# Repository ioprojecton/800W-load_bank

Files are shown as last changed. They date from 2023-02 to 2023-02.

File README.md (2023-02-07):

# 800W Load bank for generators

800W load bank for load test 1KW generators.
2steps each 400W via switch

## Authors

- [@ioprojecton](https://www.github.com/ioprojecton)

## Screenshots

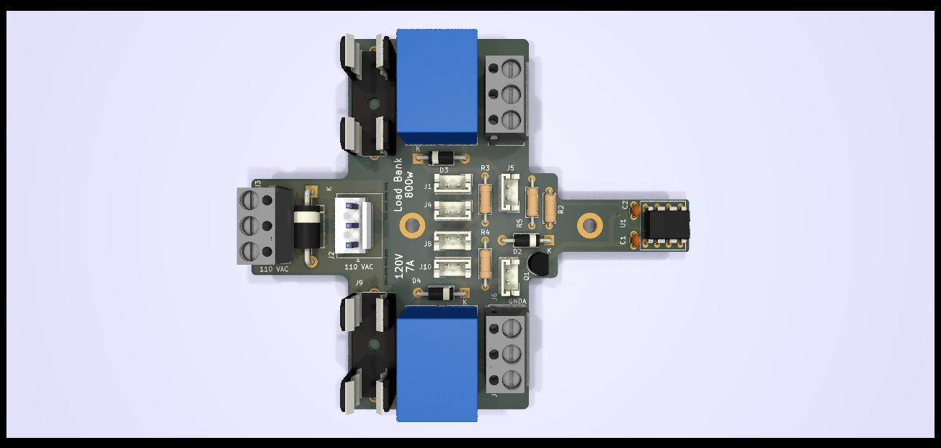
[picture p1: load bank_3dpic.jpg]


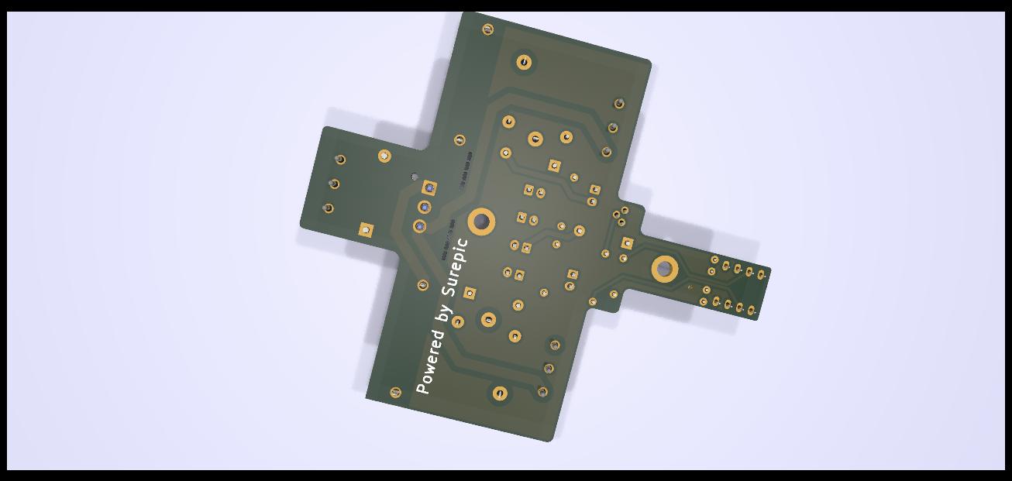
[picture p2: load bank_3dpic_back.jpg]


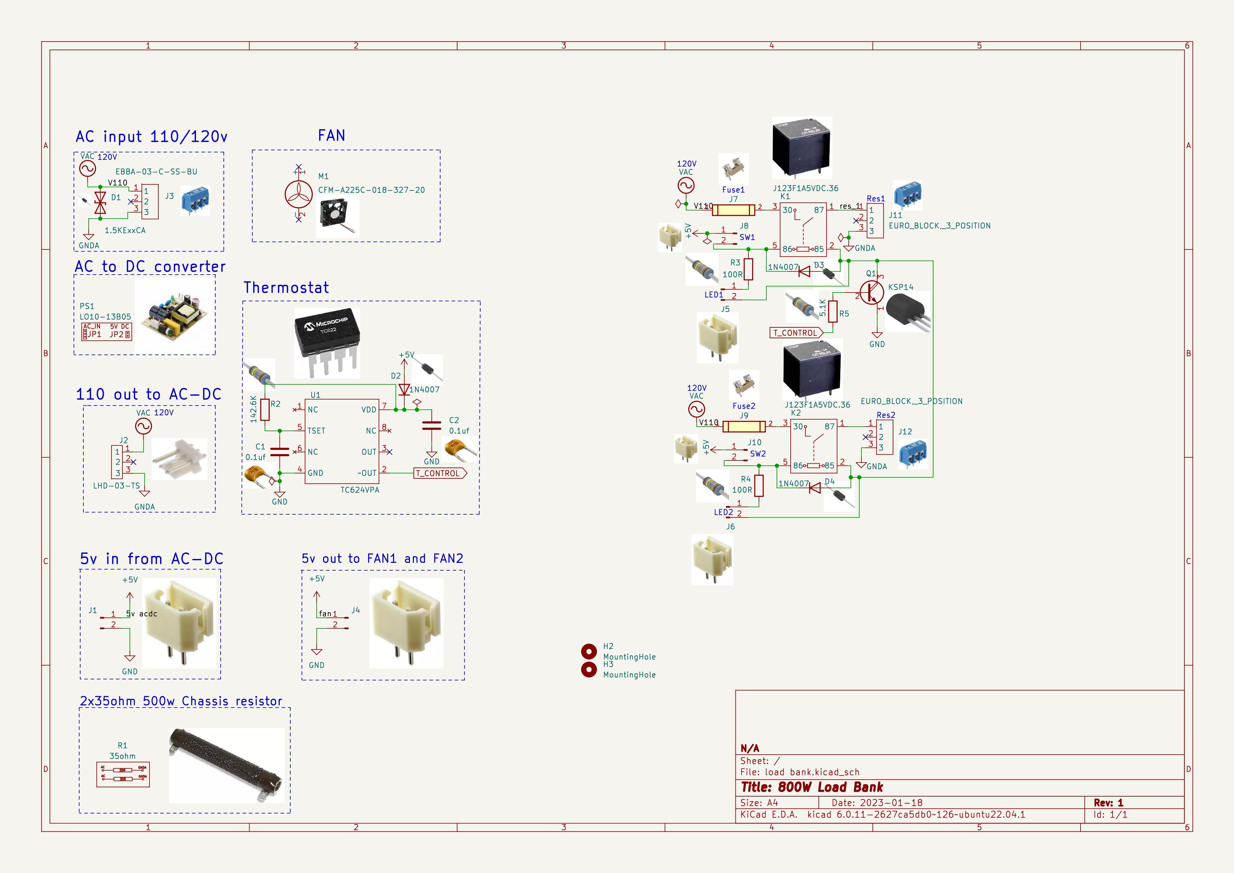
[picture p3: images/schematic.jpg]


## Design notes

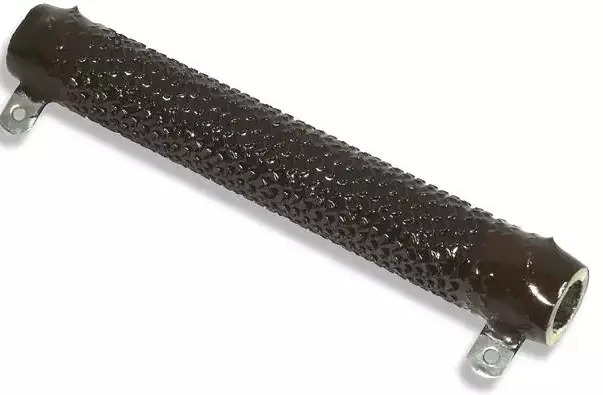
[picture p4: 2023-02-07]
images/chassis_resistor.jpg

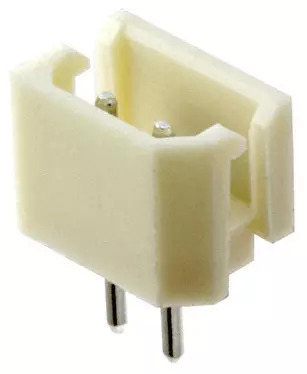
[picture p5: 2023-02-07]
images/25SH-B-02-TS.jpg

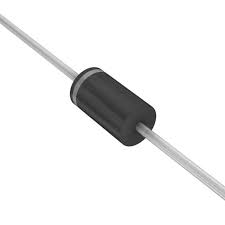
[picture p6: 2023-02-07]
images/tvs.jpeg

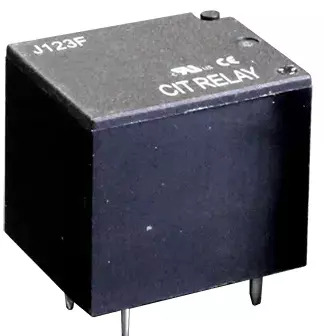
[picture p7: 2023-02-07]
images/relay.jpg

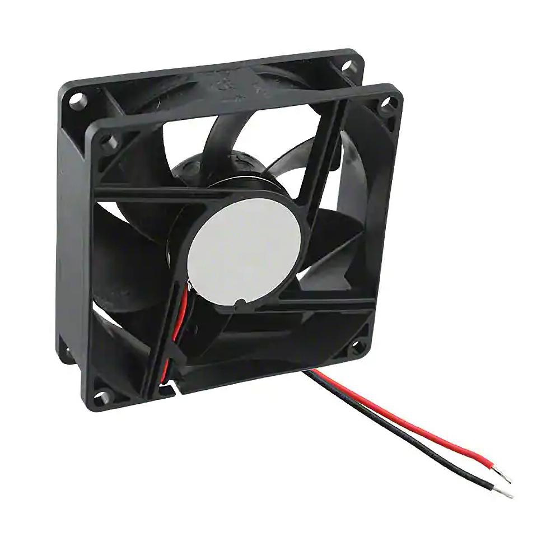
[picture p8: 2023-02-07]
images/fan.jpg

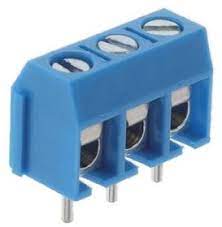
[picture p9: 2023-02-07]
images/euroblock3p.jpeg

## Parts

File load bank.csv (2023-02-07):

Source: | /home/plutus/load bank/load bank.kicad_sch
Date: | Mon 06 Feb 2023 08:38:23 PM
Tool: | Eeschema 6.0.11-2627ca5db0~126~ubuntu22.04.1
Generator: | /usr/share/kicad/plugins/bom_csv_grouped_by_value_with_fp.py
Component Count: | 31
Ref | Qnty | Value | Cmp name | Footprint | Description | Vendor
C1, C2, | 2 | 0.1uf | C | Capacitor_THT:C_Disc_D3.0mm_W1.6mm_P2.50mm | Unpolarized capacitor
D1, | 1 | 1.5KExxCA | 1.5KExxCA | Diode_THT:D_DO-201AE_P15.24mm_Horizontal | 1500W bidirectional TRANSZORB® Transient Voltage Suppressor, DO-201AE
D2, D3, D4, | 3 | 1N4007 | 1N4007 | Diode_THT:D_DO-41_SOD81_P10.16mm_Horizontal | 1000V 1A General Purpose Rectifier Diode, DO-41
J1, J4, J8, J10, | 4 | 25SH-B-02-TS | Conn_01x02_Male | Connector_JST:JST_EH_B2B-EH-A_1x02_P2.50mm_Vertical | Generic connector, single row, 01x02, script generated (kicad-library-utils/schlib/autogen/connector/)
J2, | 1 | LHD-03-TS | LHD-03-TS | Connector_JST:JST_VH_B3P-VH-FB-B_1x03_P3.96mm_Vertical
J3, | 1 | EBBA-03-C-SS-BU | EURO_BLOCK,_3_POSITION_1 | load bank:EURO_BLOCK,_3_POSITION
J5, J6, | 2 | Conn_01x02_Male | Conn_01x02_Male | Connector_JST:JST_EH_B2B-EH-A_1x02_P2.50mm_Vertical | Generic connector, single row, 01x02, script generated (kicad-library-utils/schlib/autogen/connector/)
J7, J9, | 2 | 696101000002 | 696101000002_1 | 696101000002:696101000002
J11, J12, | 2 | EURO_BLOCK,_3_POSITION | EURO_BLOCK,_3_POSITION_2 | load bank:EURO_BLOCK,_3_POSITION
K1, K2, | 2 | J123F1A5VDC.36 | J123F1A5VDC.36_1 | Relay_THT:Relay_SPST_SANYOU_SRD_Series_Form_A
M1, | 1 | CFM-A225C-018-327-20 | Fan |  | Fan
PS1, | 1 | LO10-13B05 | LO10-13B05
Q1, | 1 | KSP14 | Q_NPN_Darlington_EBC | load bank:KSP13 | NPN Darlington transistor, emitter/base/collector
R1, | 1 | 35ohm | Chassis_resistor_1
R2, | 1 | 142.6K | R | Resistor_THT:R_Axial_DIN0207_L6.3mm_D2.5mm_P7.62mm_Horizontal | Resistor
R3, R4, | 2 | 100R | R | Resistor_THT:R_Axial_DIN0207_L6.3mm_D2.5mm_P10.16mm_Horizontal | Resistor
R5, | 1 | 5.1K | R | Resistor_THT:R_Axial_DIN0207_L6.3mm_D2.5mm_P10.16mm_Horizontal | Resistor
U1, | 1 | TC624VPA | TC624VAT | load bank:DIP-8_300_ELL

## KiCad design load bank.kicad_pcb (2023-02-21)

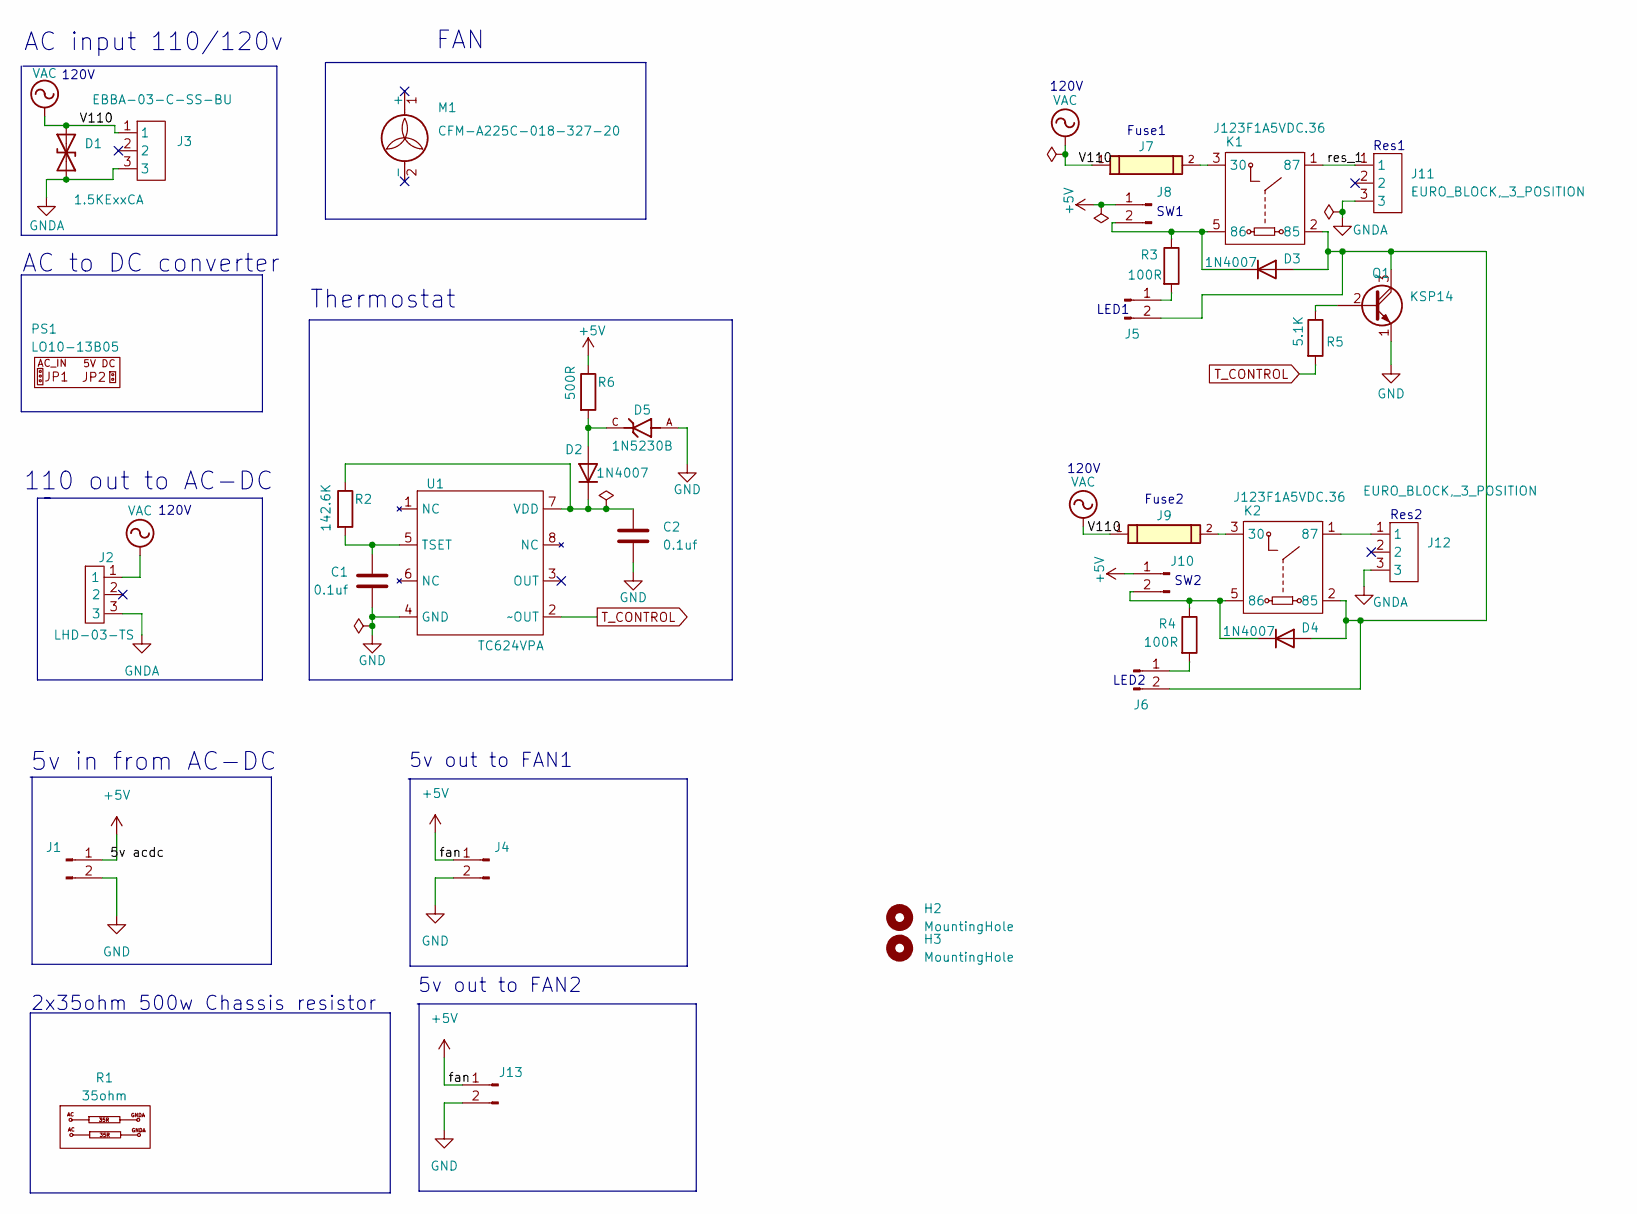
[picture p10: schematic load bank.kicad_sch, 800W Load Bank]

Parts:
C1, C2: 0.1uf; C_Disc_D3.0mm_W1.6mm_P2.50mm
D1: 1.5KExxCA; D_DO-201AE_P15.24mm_Horizontal
D2, D3, D4: 1N4007; D_DO-41_SOD81_P10.16mm_Horizontal
D5: 1N5230B; DIOAD928W47L399D179; PARTREV G1804
H2, H3: MountingHole; MountingHole_3.2mm_M3_DIN965_Pad_TopBottom
J1, J4, J8, J10, J13: 25SH-B-02-TS; JST_EH_B2B-EH-A_1x02_P2.50mm_Vertical
J2: LHD-03-TS; JST_VH_B3P-VH-FB-B_1x03_P3.96mm_Vertical
J3: EBBA-03-C-SS-BU; EURO_BLOCK,_3_POSITION
J5, J6: Conn_01x02_Male; JST_EH_B2B-EH-A_1x02_P2.50mm_Vertical
J7, J9: 696101000002; PART-NUMBER 696101000002
J11, J12: EURO_BLOCK,_3_POSITION
K1, K2: J123F1A5VDC.36; Relay_SPST_SANYOU_SRD_Series_Form_A
M1: CFM-A225C-018-327-20
PS1: LO10-13B05
Q1: KSP14; KSP13
R1: 35ohm
R2: 142.6K; R_Axial_DIN0207_L6.3mm_D2.5mm_P7.62mm_Horizontal
R3, R4: 100R; R_Axial_DIN0207_L6.3mm_D2.5mm_P10.16mm_Horizontal
R5: 5.1K; R_Axial_DIN0207_L6.3mm_D2.5mm_P10.16mm_Horizontal
R6: 500R; R_Axial_DIN0207_L6.3mm_D2.5mm_P7.62mm_Horizontal
U1: TC624VPA; DIP-8_300_ELL

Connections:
+5V: J1.1, J4.1, J8.1, J10.1, J13.1, R6.1
/res_1: J11.1, K1.1 (87)
GND: C1.1, C2.2, D5.A, J1.2, J4.2, J13.2, Q1.1 (E), U1.4 (GND)
GNDA: D1.1 (A1), J2.3, J3.3, J11.3, J12.3
unnamed: D2.2 (A), D5.C, R6.2
unnamed: C2.1, D2.1 (K), R2.1, U1.7 (VDD)
unnamed: D3.2 (A), D4.2 (A), J5.2, J6.2, K1.2 (85), K2.2 (85), Q1.3 (C)
unnamed: D3.1 (K), J8.2, K1.5 (86), R3.1
unnamed: D4.1 (K), J10.2, K2.5 (86), R4.1
unnamed: J5.1, R3.2
unnamed: J6.1, R4.2
unnamed: J7.2, K1.3 (30)
unnamed: J9.2, K2.3 (30)
unnamed: J12.1, K2.1 (87)
unnamed: Q1.2 (B), R5.1
unnamed: C1.2, R2.2, U1.5 (TSET)
T_CONTROL: R5.2, U1.2 (~OUT)
VAC: D1.2 (A2), J2.1, J3.1, J7.1, J9.1

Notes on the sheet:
110 out to AC-DC
SW1
Thermostat
AC to DC converter
Res1
SW2
LED1
Res2
AC input 110/120v
120V
2x35ohm 500w Chassis resistor
5v out to FAN2
LED2
Fuse1
5v in from AC-DC
5v out to FAN1
Fuse2
FAN

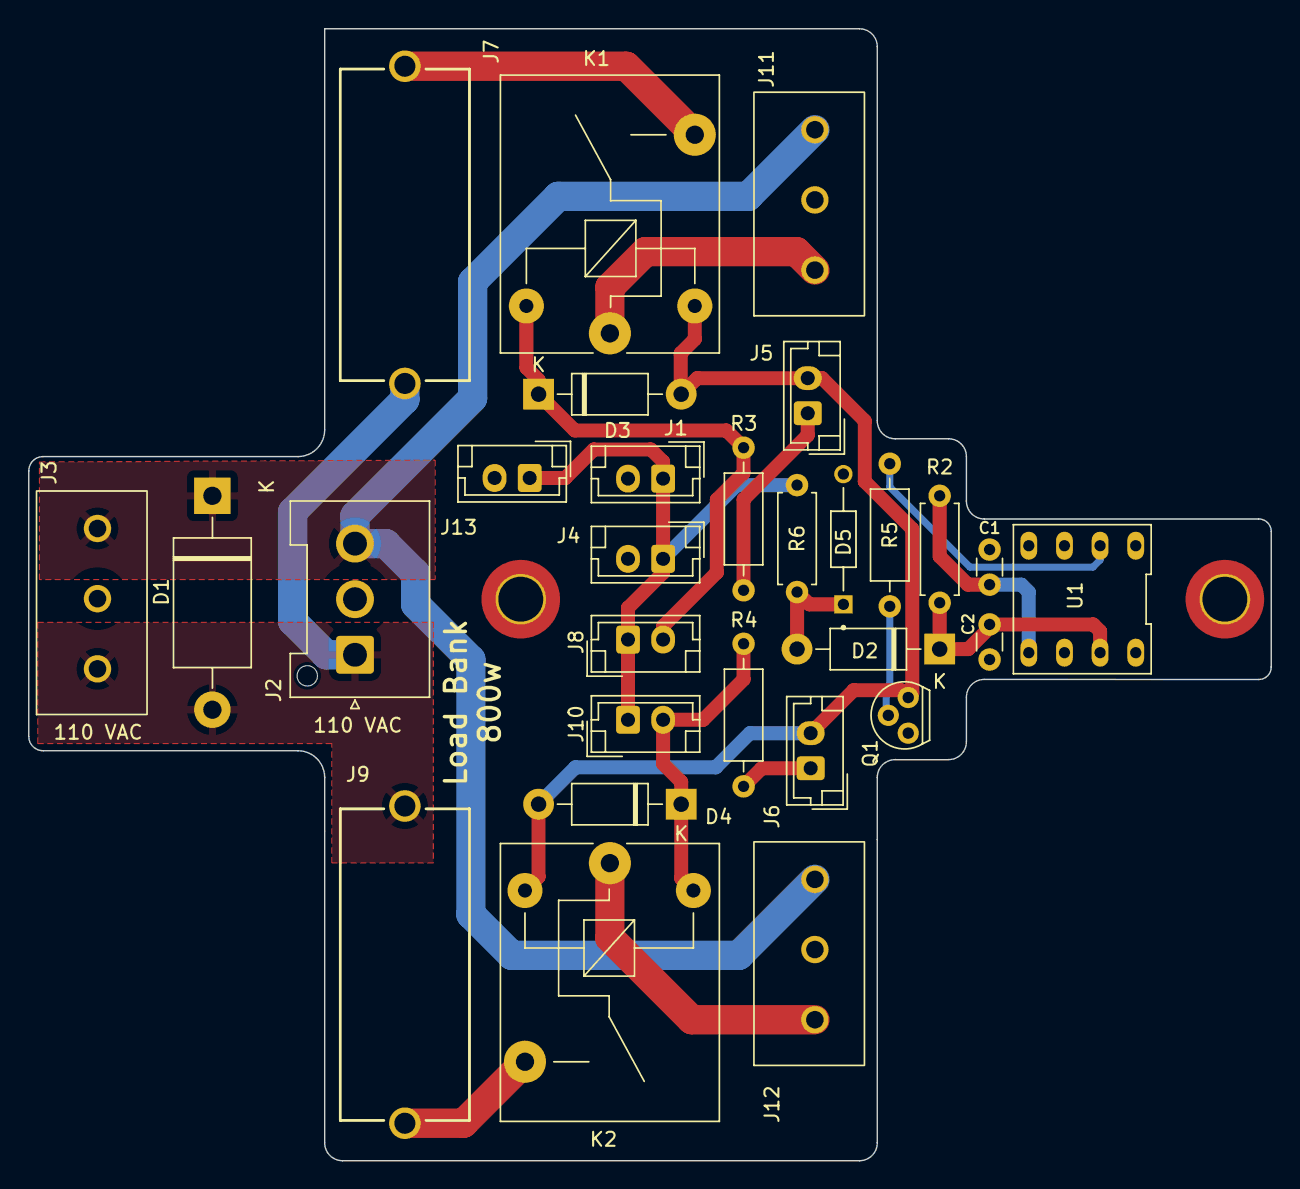
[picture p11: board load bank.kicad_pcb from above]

Board: 2 copper layers, 88.5 x 80.6 mm, 31 parts (0 on the bottom side), 18 nets.

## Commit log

2023-02-07 added BOM
    [load bank.csv]
2023-02-07 added schematic jpg
2023-02-07 added backside of pcb
2023-02-17 added second fan connector for parallel connection
    [load bank.kicad_sch]
2023-02-17 updated pcb with fan2 connector
    [load bank.kicad_pcb]
2023-02-17 added 4.7v zener + resistor to keep TC624 voltage in range
    [load bank.kicad_sch]
2023-02-17 updated pcb layout with zener and resistor
    [load bank.kicad_pcb]
2023-02-21 repositioned mounting hole
    [load bank.kicad_pcb]
